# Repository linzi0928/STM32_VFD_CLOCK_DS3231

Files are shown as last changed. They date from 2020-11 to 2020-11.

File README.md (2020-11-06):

# STM32_VFD_CLOCK_DS3231
STM32+ESP8266+DS3231搭建的简易时钟
================
This project is a simple VFD clock.  
**Hardware Configuration:**  
* Master: STM32F103C8T6  
* Clock chip: DS3231  
* Wifi Model: Ai-Thinker ESP-07 (ESP8266)(Optional)  
* PCB Project: Altium Designer  
* MCU Project: Keil uVision 5  
* 3D Model Project: SolidWorks  
**bilibili号: GIE工作室，欢迎关注获得超多干货**  
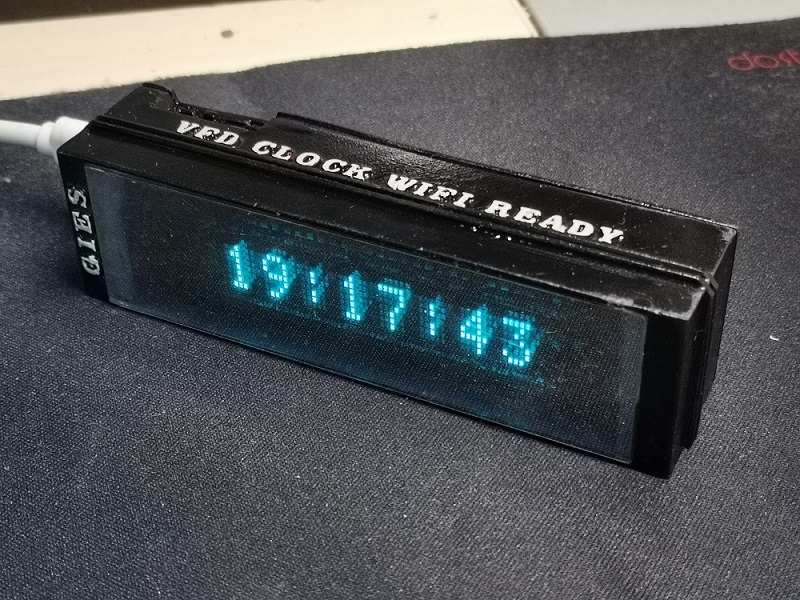
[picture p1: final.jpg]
Final


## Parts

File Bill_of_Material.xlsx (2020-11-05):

VFD时钟材料清单
Comment | Description | Designator | Footprint | LibRef | Quantity
0.1uf | 无极性贴片电容 | C1, C3, C5, C7, C11, C12, C13 | C 0603_L | C | 7 | 绿：常规器件
10uf | 无极性贴片电容 | C2, C4, C8 | C 0603_L | C | 3 | 黄：特殊器件
22pF | 无极性贴片电容 | C6, C9 | C 0603_L | C | 2 | 红：定制器件
1uf | 无极性贴片电容 | C10 | C 0603_L | C | 1
1220 | 贴片微型电池座 | CR1 | CR1220_A | CR-3V | 1
6V 0.5A | 贴片保险丝（可直接短接） | F1 | FU 0805 | FU | 1
HDR-1X7 | 7P 2.54mm排母 | JP1 | HDR2.54-LI-7P | Header 7 | 1
HDR-1X7 | 7P 2.54mm排针 |  |  |  | 1
HDR-1X4 | 4P 2.54mm排针 | JP2 | HDR2.54-LI-4P | Header 4 | 1
冰蓝 | 贴片LED | LED1 | LED 0603B | LED-SMD | 1
ESP8266-07 | 串口 WIFI模块，ESP-07 | M1 | ESP-07 | ESP8266-07 | 1
microUSB | 电源接口 | P1 | microUSB | microUSB | 1
10K | 贴片电阻 | R1, R5, R6 | R 0603_L | R | 3
1K | 贴片电阻 | R2 | R 0603_L | R | 1
4.7K | 贴片网络排阻 | RP1 | RCA-8P4R-0603 | R-8P4R | 1
DS3231M+ | 时钟芯片 | U1 | SOP8_N | DS3231M+ | 1
STM32F103C8 | 单片机 | U2 | LQFP48 7X7_N | STM32F103C8 | 1
AMS1117-3V3 | 三端稳压芯片 | V1 | SOT223_L | AMS1117 | 1
8M | 4脚无源晶振 | X1 | OSC 3225-4P | XTAL-4P | 1
10mm | 双通M3铜柱 | - | - |  | 2
1220 | 纽扣电池 | - | - |  | 1
- | M3螺母 |  |  |  | 2
10mm | M3螺丝 | - | - |  | 4
SLLB510100 | 操作杆和按动操作型开关 | SW1 | SLLB510100 | SLLB5 | 1
VFD显示模块 8位点阵显示模块 | 屏幕 |  |  |  | 1
25mm*90mm厚2mm | 亚克力半透镜 |  |  |  | 1
给定STL图纸 | 3D打印 |  |  |  | 1

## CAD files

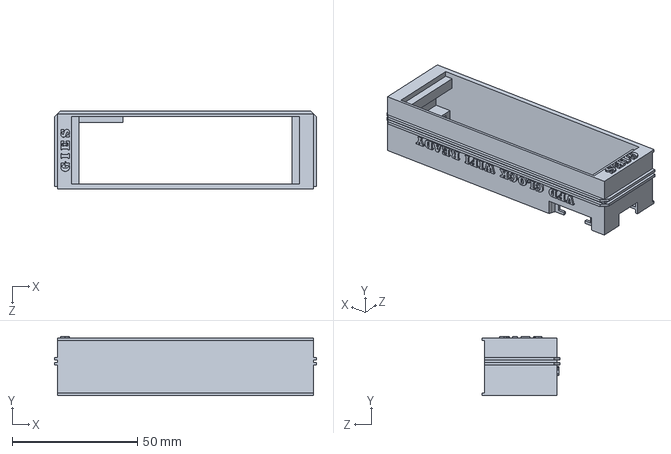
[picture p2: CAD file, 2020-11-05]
3D Model/VFD_MainSheel.SLDPRT
104.4 x 23.7 x 31.2 mm

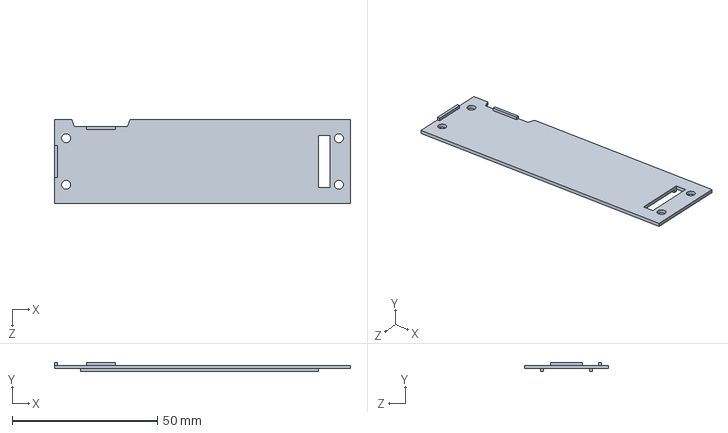
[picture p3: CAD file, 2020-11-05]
3D Model/VFD_BackCover.SLDPRT
102.0 x 3.20 x 29.0 mm

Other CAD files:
3D Model/VFD_BackCover.STL
3D Model/VFD_MainSheel.STL

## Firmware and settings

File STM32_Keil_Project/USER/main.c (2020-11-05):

/*************************************************************************************************************
舸轮综合电子工作室(GIE工作室)        出品
Gearing Interated Electronics Studio

8位VFD时钟驱动程序

关注B站UP主：GIE工作室 获得更多视频资源及动态

2020-10-14第一版 by Vanilla's Lab
2020-10-22第二版 by GIE Studio
*************************************************************************************************************/
#include "sys.h"
#include "delay.h"
#include "usart.h"
#include "string.h"
#include "VFD6302.H"
#include "gpio.h"
#include "i2c.h"
#include "ds3231.h"
#include "timer.h"
#define READ_PUSH PAin(0)
#define READ_CCW PAin(1)
#define READ_CW PAin(2)
int second_last;
int sec_flag,wifi_flag=0;
char dateD[]="10-21 W3";
char timeD[]="00:00:00";
int tyear,tdate,tmon,tweek,tmin,tsec,thour,modeD=0;
extern u8 getTime(void);
extern void ESP8266_Init(void);
extern void One_Step(int dir);
extern clock localTime;
extern clock NetTime;
u8 i=0,ix=0;
void time_refresh(void);
void wifi_calc(void);
int main(void)
{		
	//delay_init();	    	 //延时函数初始化	  
	NVIC_Configuration(); 	 //设置NVIC中断分组2:2位抢占优先级，2位响应优先级
	
	VFD_IO_Init();
	VFD_init();
	uart_init(115200);
	TIM3_Int_Init(625,31);//时间显示刷新中断
	TimeValue.year=0x2020;//如果下面那行不打开，这些初始时间均无效	
	TimeValue.month=0x10;
	TimeValue.week=0x05;
	TimeValue.date=0x25;
	TimeValue.hour=0x23;
	TimeValue.minute=0x59;
	TimeValue.second=0x55;
	//DS3231_Time_Init(&TimeValue);//调试用，程序强制写入时间值
	LED_BLUE=0;
	while(1)
	{	
		for(ix=80;ix>0;ix--)
		{
		time_refresh();
		S1201_WriteStr(0,timeD);
		wifi_calc();			
		delay_ms(50);		
		}
	if(modeD==0)
	{	
			for(ix=200;ix>0;ix--)
			{
			bri_set(ix);
			delay_ms(1);
			if((ix%7)==0)
				{
					time_refresh();
					wifi_calc();
					S1201_WriteStr(0,timeD);
				}
			}
			S1201_WriteStr(0,dateD);
			for(ix=0;ix<200;ix++)
			{
			bri_set(ix);
			delay_ms(1);
			}
			for(ix=95;ix>0;ix--)
			{
			wifi_calc();
			delay_ms(10);
			}
			for(ix=200;ix>0;ix--)
			{
			wifi_calc();
			bri_set(ix);
			delay_ms(1);
			}
			for(ix=0;ix<200;ix++)
			{
			bri_set(ix);
			delay_ms(1);
			if((ix%7)==0)
				{
					time_refresh();
					wifi_calc();
					S1201_WriteStr(0,timeD);
				}
			}
		}
	}
 }
void time_refresh(void)
{
		Time_Handle();//获取时间
 		tmon=10*(TimeValue.month/16)+(TimeValue.month%16);
		tdate=10*(TimeValue.date/16)+(TimeValue.date%16);
		tweek=TimeValue.week;
		if(tweek==0)
			tweek=7;
		tmin=10*(TimeValue.minute/16)+(TimeValue.minute%16);
		tsec=10*(TimeValue.second/16)+(TimeValue.second%16);
		thour=10*(TimeValue.hour/16)+(TimeValue.hour%16);
		
		dateD[0]=tmon/10+48;dateD[1]=tmon%10+48;
		dateD[3]=tdate/10+48;dateD[4]=tdate%10+48;
		dateD[7]=tweek+48;
		timeD[0]=thour/10+48;timeD[1]=thour%10+48;
		timeD[3]=tmin/10+48;timeD[4]=tmin%10+48;
		timeD[6]=tsec/10+48;timeD[7]=tsec%10+48;
}
void wifi_calc(void)
{
	if(wifi_flag==1)
		{
			S1201_WriteStr(0,"NTP_CALC");
			ESP8266_Init();//初始化8266 wifi模块，连接到路由器
			S1201_WriteStr(0,"NTP_CONN");
			if(getTime())S1201_WriteStr(0,"NTP_ERR");//获取时间
			else 
			{
				S1201_WriteStr(0,"NET_GET");//获取时间成功后对本地时钟进行校准
				TimeValue.month=(((localTime.month+1)/10)<<4)+(((localTime.month+1)%10)&0x0F);//注意NTP的月份是0-11所以需要+1，然后通过移位转换为BCD码才能写入3231
				TimeValue.date=((localTime.day/10)<<4)+((localTime.day%10)&0x0F);
				TimeValue.hour=((localTime.hour/10)<<4)+((localTime.hour%10)&0x0F);
				TimeValue.minute=((localTime.min/10)<<4)+((localTime.min%10)&0x0F);
				TimeValue.second=((localTime.sec/10)<<4)+((localTime.sec%10)&0x0F);
				TimeValue.week=localTime.date;
				DS3231_Time_Init(&TimeValue);//向3231校准本地时间
				S1201_WriteStr(0,"TIME_GET");
				delay_ms(1000);
				wifi_flag=0;
			}
		}
		if(sec_flag==1)
		{
			sec_flag=0;
			LED_BLUE=~LED_BLUE;
		}
}
void clock_irq(void)
{
	int menu_pos=0,hourk,mink,datek,monk,weekk;
	char timeDk[2]="  ";
	if(READ_PUSH==0)
	{
		delay_ms(10);
		if(READ_PUSH==0)
		{
			bri_set(255);
			if(wifi_flag==1)
				{
					S1201_WriteStr(0,"CANCELED");
					delay_ms(1000);
					__set_FAULTMASK(1);
					NVIC_SystemReset(); 
				}
			S1201_WriteStr(0,">MENU   ");
			delay_ms(1000);
			while(READ_PUSH==0);
			while(1)
				{
					if(READ_CW==0)
					{
						menu_pos++;
					while(READ_CW==0);
					if (menu_pos>2)
						menu_pos=0;
					}
					if(READ_CCW==0)
					{
						menu_pos--;
					while(READ_CCW==0);
					if (menu_pos<0)
						menu_pos=2;
					}
					if(menu_pos==0)
					{
					S1201_WriteStr(0,">BY WIFI ");
					if(READ_PUSH==0)
						{
							delay_ms(10);
								if(READ_PUSH==0)
								{
									while(1)
									{
									S1201_WriteStr(0,"WIFIINIT");
									delay_ms(1000);
									while(READ_PUSH==0);
									wifi_flag=1;
									return;
									}
								}
						}
					}
					if(menu_pos==1)
					{
					S1201_WriteStr(0,">BY HAND ");
							if(READ_PUSH==0)
								{
									delay_ms(10);
									if(READ_PUSH==0)
									{
										while(READ_PUSH==0);
										hourk=thour;
										mink=tmin;
										monk=tmon;
										datek=tdate;
										weekk=tweek;
										S1201_WriteStr(0,timeD);
										while(1)
										{
											ix=10;
											while(ix--)
											{
												delay_ms(10);
												if(READ_CW==0)
												{
													while(READ_CW==0);
													hourk++;
													if(hourk>23)
														hourk=0;
												}
												if(READ_CCW==0)
												{
													while(READ_CCW==0);
													hourk--;
													if(hourk<0)
														hourk=23;
												}
												timeDk[0]=hourk/10+48;
												timeDk[1]=hourk%10+48;
												S1201_WriteStr(0,timeDk);
											}
											ix=10;
											while(ix--)
											{
												delay_ms(10);
												if(READ_CW==0)
												{
													while(READ_CW==0);
													hourk++;
													if(hourk>23)
														hourk=0;
												}
												if(READ_CCW==0)
												{
													while(READ_CCW==0);
													hourk--;
													if(hourk<0)
														hourk=23;
												}
												timeDk[0]=hourk/10+48;
												timeDk[1]=hourk%10+48;
												S1201_WriteStr(0,"  ");
											}
											if(READ_PUSH==0)
											{
												while(READ_PUSH==0);
												S1201_WriteStr(0,timeDk);
												while(1)
												{
																ix=10;
																while(ix--)
																{
																	delay_ms(10);
																	if(READ_CW==0)
																	{
																		while(READ_CW==0);
																		mink++;
																		if(mink>59)
																			mink=0;
																	}
																	if(READ_CCW==0)
																	{
																		while(READ_CCW==0);
																		mink--;
																		if(mink<0)
																			mink=59;
																	}
																	timeDk[0]=mink/10+48;
																	timeDk[1]=mink%10+48;
																	S1201_WriteStr(3,timeDk);
																}
																ix=10;
																while(ix--)
																{
																	delay_ms(10);
																	if(READ_CW==0)
																	{
																		while(READ_CW==0);
																		mink++;
																		if(mink>59)
																			mink=0;
																	}
																	if(READ_CCW==0)
																	{
																		while(READ_CCW==0);
																		mink--;
																		if(mink<0)
																			mink=59;
																	}
																	timeDk[0]=mink/10+48;
																	timeDk[1]=mink%10+48;
																	S1201_WriteStr(3,"  ");
																}
																if(READ_PUSH==0)
																{
																	delay_ms(10);
																	if(READ_PUSH==0)
																	{
																		S1201_WriteStr(0,dateD);
																		while(1)
																		{
																					ix=10;
																					while(ix--)
																					{
																						delay_ms(10);
																						if(READ_CW==0)
																						{
																							while(READ_CW==0);
																							monk++;
																							if(monk>12)
																								monk=1;
																						}
																						if(READ_CCW==0)
																						{
																							while(READ_CCW==0);
																							monk--;
																							if(monk<1)
																								monk=12;
																						}
																						timeDk[0]=monk/10+48;
																						timeDk[1]=monk%10+48;
																						S1201_WriteStr(0,timeDk);
																					}
																					ix=10;
																					while(ix--)
																					{
																						delay_ms(10);
																						if(READ_CW==0)
																						{
																							while(READ_CW==0);
																							monk++;
																							if(monk>12)
																								monk=1;
																						}
																						if(READ_CCW==0)
																						{
																							while(READ_CCW==0);
																							monk--;
																							if(monk<1)
																								monk=12;
																						}
																						timeDk[0]=monk/10+48;
																						timeDk[1]=monk%10+48;
																						S1201_WriteStr(0,"  ");
																					}
																					if(READ_PUSH==0)
																								{
																									delay_ms(10);
																									if(READ_PUSH==0)
																									{
																										S1201_WriteStr(0,timeDk);
																										while(1)
																										{
																													ix=10;
																													while(ix--)
																													{
																														delay_ms(10);
																														if(READ_CW==0)
																														{
																															while(READ_CW==0);
																															datek++;
																															if(datek>31)
																																datek=1;
																														}
																														if(READ_CCW==0)
																														{
																															while(READ_CCW==0);
																															datek--;
																															if(datek<1)
																																datek=31;
																														}
																														timeDk[0]=datek/10+48;
																														timeDk[1]=datek%10+48;
																														S1201_WriteStr(3,timeDk);
																													}
																													ix=10;
																													while(ix--)
																													{
																														delay_ms(10);
																														if(READ_CW==0)
																														{
																															while(READ_CW==0);
																															datek++;
																															if(datek>31)
																																datek=1;
																														}
																														if(READ_CCW==0)
																														{
																															while(READ_CCW==0);
																															datek--;
																															if(datek<1)
																																datek=31;
																														}
																														timeDk[0]=datek/10+48;
																														timeDk[1]=datek%10+48;
																														S1201_WriteStr(3,"  ");
																													}
																																			if(READ_PUSH==0)
																																			{
																																				delay_ms(10);
																																				if(READ_PUSH==0)
																																				{
																																					S1201_WriteStr(3,timeDk);
																																					while(1)
																																					{
																																								ix=10;
																																								while(ix--)
																																								{
																																									delay_ms(10);
																																									if(READ_CW==0)
																																									{
																																										while(READ_CW==0);
																																										weekk++;
																																										if(weekk>7)
																																											weekk=1;
																																									}
																																									if(READ_CCW==0)
																																									{
																																										while(READ_CCW==0);
																																										weekk--;
																																										if(weekk<1)
																																											weekk=7;
																																									}
																																									timeDk[0]=weekk+48;
																																									S1201_WriteStr(7,timeDk);
																																								}
																																								ix=10;
																																								while(ix--)
																																								{
																																									delay_ms(10);
																																									if(READ_CW==0)
																																									{
																																										while(READ_CW==0);
																																										weekk++;
																																										if(weekk>7)
																																											weekk=1;
																																									}
																																									if(READ_CCW==0)
																																									{
																																										while(READ_CCW==0);
																																										weekk--;
																																										if(weekk<1)
																																											weekk=7;
																																									}
																																									timeDk[0]=weekk+48;
																																									S1201_WriteStr(7,"  ");
																																								}
																																								if(READ_PUSH==0)
																																								{
																																									delay_ms(10);
																																									if(READ_PUSH==0)
																																									{
																																										S1201_WriteStr(0,"CALCOVER");
																																										TimeValue.month=(monk/10)*16+monk%10;
																																										if(weekk>6)
																																											weekk=0;
																																										TimeValue.week=(weekk/10)*16+weekk%10;
																																										TimeValue.date=(datek/10)*16+datek%10;
																																										TimeValue.hour=(hourk/10)*16+hourk%10;
																																										TimeValue.minute=(mink/10)*16+mink%10;
																																										DS3231_Time_Init(&TimeValue);
																																										delay_ms(700);
																																										return;
																																									}
																																								}
																																					}
																																				}
																																			}
																										}
																									}
																								}
																		}
																	}
																}
												}
											}
										}
									}
								}
					}
					if(menu_pos==2)
					{
					S1201_WriteStr(0,">RETURN  ");
							if(READ_PUSH==0)
							{
								delay_ms(10);
									if(READ_PUSH==0)
									{
										while(1)
										{
											delay_ms(10);
											while(READ_PUSH==0);
											return;
										}
									}
							}
					}
			}
		}
	}
	if(READ_CCW==0)
	{
		delay_ms(10);
		if(READ_CCW==0)
		{
			while(READ_CCW==0);
			bri_set(255);
			if(modeD==1)
			{
				modeD=0;
				S1201_WriteStr(0,"MODE  01");
				delay_ms(1000);
			}
			else
			{
				modeD=1;
				S1201_WriteStr(0,"MODE  02");
				delay_ms(1000);
			}
		}
	}
}

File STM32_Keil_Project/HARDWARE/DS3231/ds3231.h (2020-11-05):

	  /******************************************************************************
* @ File name --> ds3231.c
* @ Author    --> By@ Sam Chan
* @ Version   --> V1.0
* @ Date      --> 02 - 01 - 2014
* @ Brief     --> 高精度始终芯片DS3231驱动函数
*
* @ Copyright (C) 20**
* @ All rights reserved
*******************************************************************************
*
*                                  File Update
* @ Version   --> V1.
* @ Author    -->
* @ Date      -->
* @ Revise    -->
*
******************************************************************************/

#ifndef _ds3231_h_
#define _ds3231_h_

/******************************************************************************
                                外部函数头文件                        
******************************************************************************/

#include "stm32f10x.h"

#include "i2c.h"

/******************************************************************************
                         DS3231日历时钟寄存器结构定义                          
******************************************************************************/
typedef struct
{			   
	u16 year;//年
	u8 month;//月
	u8 week;//星期
	u8 date;//日
	int hour;//小时
	int minute;//分钟
	int second;//秒钟
}Time_Typedef;

extern Time_Typedef TimeValue;	//定义时间数据缓存
extern u8 Time_Buffer[7];	//时间日历数据缓存

extern u8 Display_Time[8];	//显示时间格式
extern u8 Display_Date[13];	//显示日期格式

/******************************************************************************
                                  参数宏定义                       
******************************************************************************/

#define DS3231_YEARDATA                  (u16)0x2015	//年结构，如果是19xx年、21xx年的话请修改这个数值即可

#define DS3231_ADD_BASS					0xd0	//器件基地址

#define DS3231_Write_ADD				(DS3231_ADD_BASS | 0x00)	//写DS3231
#define DS3231_Read_ADD					(DS3231_ADD_BASS | 0x01)	//读DS3231

/******************************************************************************
                              参数寄存器地址宏定义                    
******************************************************************************/

#define Address_second					0x00	//秒
#define Address_minute					0x01	//分
#define Address_hour					0x02	//时
#define Address_week					0x03	//星期
#define Address_date					0x04	//日
#define Address_month					0x05	//月
#define Address_year					0x06	//年

#define Address_second_Alarm1			0x07	//秒闹铃
#define Address_minute_Alarm1			0x08	//分闹铃
#define Address_hour_Alarm1				0x09	//时闹铃
#define Address_week_Alarm1				0x0a	//日闹铃、星期闹铃

#define Address_minute_Alarm2			0x0b	//分闹铃
#define Address_hour_Alarm2				0x0c	//时闹铃
#define Address_week_Alarm2				0x0d	//日闹铃、星期闹铃


#define Address_control					0x0e	//控制
#define Address_control_status			0x0f	//控制和状态标志

#define Address_offset					0x10	//Aging Offset

#define Address_temp_MSB				0x11	//温度高8位
#define Address_temp_LSB				0x12	//温度低8位

/******************************************************************************
                             时间参数屏蔽无效位宏定义                 
******************************************************************************/

#define Shield_secondBit			0x7f
#define Shield_minuteBit			0x7f
#define Shield_hourBit				0x3f
#define Shield_weekBit				0x07
#define Shield_dateBit				0x3f
#define Shield_monthBit				0x1f

/******************************************************************************
                                 参数命令定义                      
******************************************************************************/

//小时寄存器
#define Hour_Mode12					(1<<6)	//12小时格式
#define Hour_Mode24					(0<<6)	//24小时格式

//秒闹铃寄存器1
#define Alarm_second_open			(1<<7)	//秒闹铃开
#define Alarm_second_close			(0<<7)	//秒闹铃关

//分闹铃寄存器1&2
#define Alarm_minute_open			(1<<7)	//分闹铃开
#define Alarm_minute_close			(0<<7)	//分闹铃关

//时闹铃寄存器1&2（可设置为12小时模式或者24小时模式）
#define Alarm_hour_open12			(3<<6)	//时闹铃开，12小时格式
#define Alarm_hour_close12			(1<<6)	//时闹铃关，24小时格式

#define Alarm_hour_open24			(2<<6)	//时闹铃开，12小时格式
#define Alarm_hour_close24			(0<<6)	//时闹铃关，24小时格式

//星期、日闹铃寄存器1&2（可选择星期闹铃或则日期闹铃）
#define Alarm_week_open				(3<<6)	//星期闹铃开
#define Alarm_week_close			(1<<6)	//星期闹铃关

#define Alarm_date_open				(2<<6)	//星期闹铃开
#define Alarm_date_close			(0<<6)	//星期闹铃关


//晶振控制寄存器
#define OSC_Enable					(0<<7)	//启动晶振
#define OSC_Disable					(1<<7)	//停止晶振

#define SET_BBSQW					(1<<6)	//Vbat pin
#define RESET_BBSQW					(0<<6)	//int/sqw高阻

#define Temp_CONV_SET				(1<<5)	//强制温度转换位数字码
#define Temp_CONV_Clear				(0<<5)

#define SQW_OUT1Hz					(0<<3)	//1Hz
#define SQW_OUT1024Hz				(1<<3)	//1.024KHz
#define SQW_OUT4096Hz				(2<<3)	//4.096KHz
#define SQW_OUT8192Hz				(3<<3)	//8.192KHz

#define OUTPUT_INTSQW				(0<<2)	//输出方波，上电该位置1（INTCN位）

#define A2IE_Enable					(1<<1)	//enable alarm 2
#define A2IE_Disable				(0<<1)	//disable alarm 2

#define A1IE_Enable					(1<<0)	//enable alarm 1
#define A1IE_Disable				(0<<0)	//disable alarm 1

//控制、状态寄存器
#define Clear_OSF_Flag				(0<<7)	//clear OSF flag

#define Enable_OSC32768				(1<<3)	//EN32KHz EN
#define Disable_OSC32768			(0<<3)	//EN32KHz高阻

#define Clear_A2IE_Flag				(0<<1)	//清除闹铃2中断标志
#define Clear_A1IE_Flag				(0<<0)	//清除闹铃2中断标志

/******************************************************************************
                                外部功能函数                      
******************************************************************************/

u8 DS3231_Check(void);	//DS3231检测函数

void DS3231_Write_Byte(u8 REG_ADD,u8 dat);	//DS3231某寄存器写入一个字节数据

u8 DS3231_Read_Byte(u8 REG_ADD);	//DS3231某寄存器读取一个字节数据

void DS3231_ReadWrite_Time(u8 mode);	//DS3231读取或者写入时间信息

void DS3231_Time_Init(Time_Typedef *TimeVAL);	//时间日历初始化

void Time_Handle(void);	//时间日历数据处理函数


void DS3231_Read_Temp(u8 *Temp);	//读取芯片温度寄存器
extern int second_last;
extern int sec_flag;
#endif
